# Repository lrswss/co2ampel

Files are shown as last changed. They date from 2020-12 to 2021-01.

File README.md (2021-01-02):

## CO2-Ampel

<p align="center">
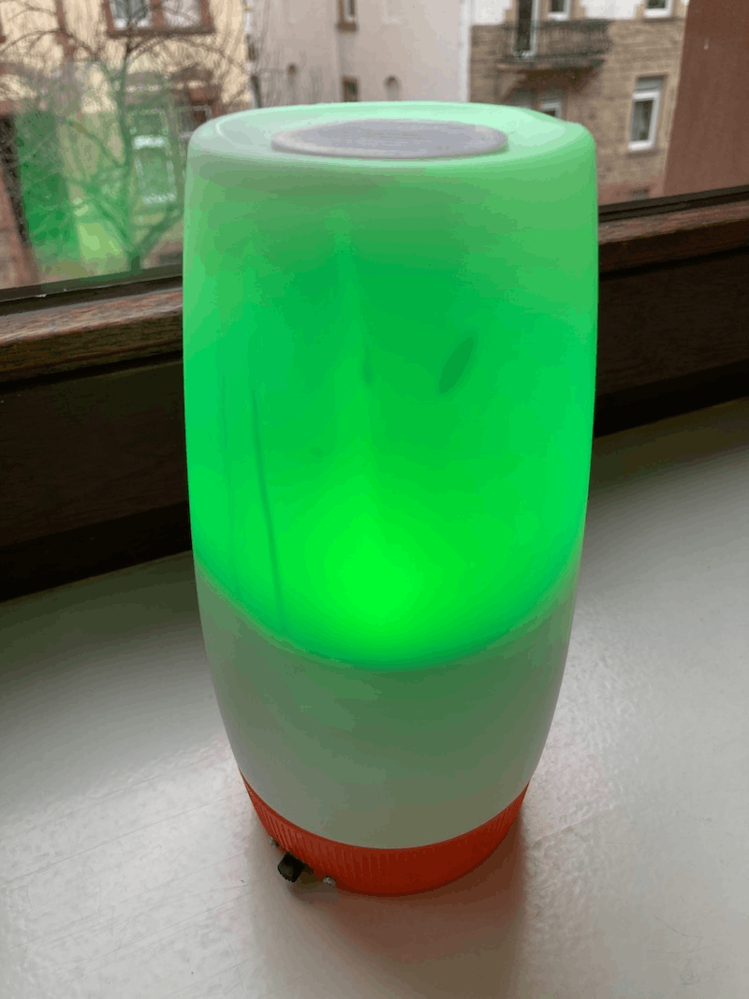
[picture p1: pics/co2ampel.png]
CO2Ampel

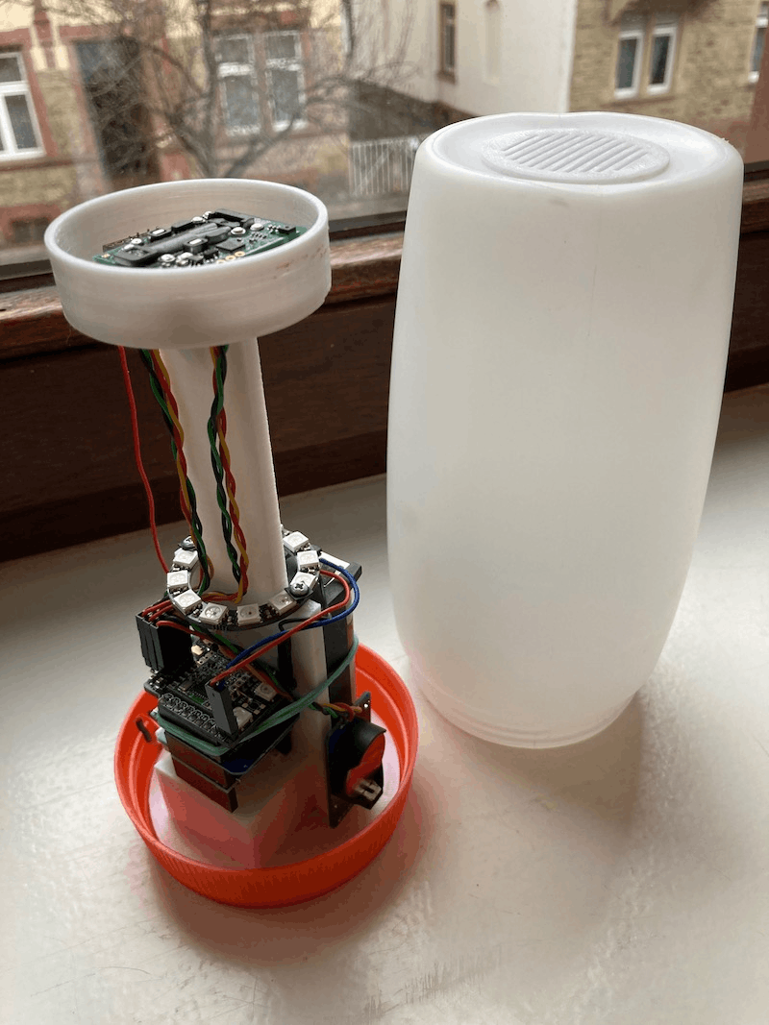
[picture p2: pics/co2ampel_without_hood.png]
CO2-Ampel disassembled (front)

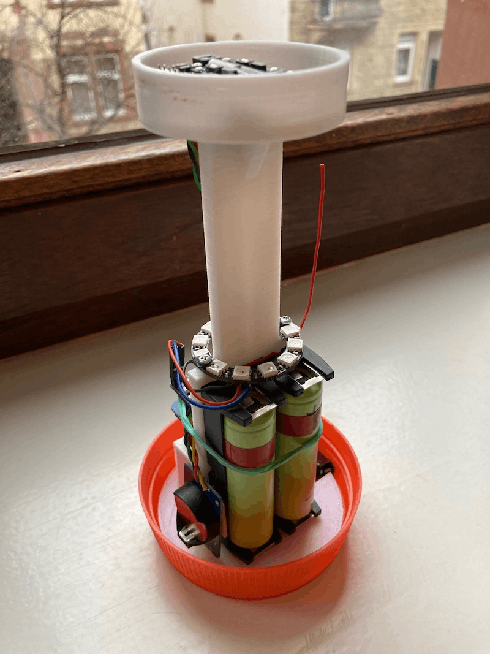
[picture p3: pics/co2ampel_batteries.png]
CO2-Ampel disassembled (back)

</p>

Yet another CO<sub>2</sub>-Ampel based on an ESP8266 (Wemos D1 mini) to continuously
measure CO<sub>2</sub> concentration indoors with a [SCD30](https://www.sensirion.com/en/environmental-sensors/carbon-dioxide-sensors/carbon-dioxide-sensors-CO<sub>2</sub>/) CO<sub>2</sub> sensor accompanied by a [BME280](https://www.bosch-sensortec.com/products/environmental-sensors/humidity-sensors-bme280/)
for temperature, humidity and air pressure readings. Current air condition
(good, medium, critical, bad) is shown using a NeoPixel ring with WS2812
LEDs illuminating the device in either green, yellow or red.

Unlike other devices this one runs on two 18650 Li-Ion batteries, offers
a sophisticated web interface for configuration, live sensor readings
and OTA firmware updates. Sensor data can be logged to local flash
(LittleFS), retrieved RESTful, published using MQTT or even transmitted
with LoRaWAN if a [RFM95 shield](https://github.com/hallard/WeMos-Lora)
is installed.

## Hardware components

* [SCD30 CO2 sensor](https://www.sensirion.com/en/environmental-sensors/carbon-dioxide-sensors/carbon-dioxide-sensors-CO<sub>2</sub>/)
* [BME280 break-out board](https://www.aliexpress.com/wholesale?SearchText=bme280&opensearch=true)
* [Wemos D1 mini board](https://escapequotes.net/esp8266-wemos-d1-mini-pins-and-diagram/)
* [Wemos Battery Shield](https://www.wemos.cc/en/latest/d1_mini_shield/battery.html)
* [Wemos ProtoBoard Shield](https://www.wemos.cc/en/latest/d1_mini_shield/protoboard.html) or
[LoRa Shield](https://github.com/hallard/WeMos-Lora)
* [DS3231 AT24C32 RTC Module](https://de.aliexpress.com/w/wholesale-ds3231.html)
* [NeoPixel ring with 12 WS2812 LEDs](https://www.aliexpress.com/w/wholesale-rgb%20led%20ring%2012%20bits%20ws2812.html)
* 3-pin slide switch
* 2 x 18650 rechargeable Li-Ion cells
* 2 x single-slot 18650 battery holders
* 5 x Dupont cables with female connector (3 x 4-pin, 1 x 2-pin, 1 x 1-pin)
* 2pin JST PH2.0 female plug
* 2.54mm single row pin headers for Dupont connectors

Looking around for a suitable housing for the CO<sub>2</sub>-Ampel we (my son and I)
spontaneously choose [this](https://www.ovomaltine.de/produkte/ovomaltine-pulver-dose)
because it was almost empty, pretty robust and seemed perfect in respect
to shape and size. :wink:

To help stack all components inside the translucent plastic tin I designed
a  simple [3D printed inner frame](3d-parts/inner-frame.png) which has a
place for all components and is  glued into the orange lid. The SCD30 and
BME280 sensors are placed into a seperate [3D printed sensor-mount](3d-parts/sensor-mount.png)
which is glued on top of the frame **after** the NeoPixel ring has been screwed
onto the frame. Air ventilation is achieved by a [3D printed grille](3d-parts/ventilation_grille.png)
pressed into a 40 mm hole cut into the rather thick bottom of the
plastic tin.

## Putting it all together

<p align="center">
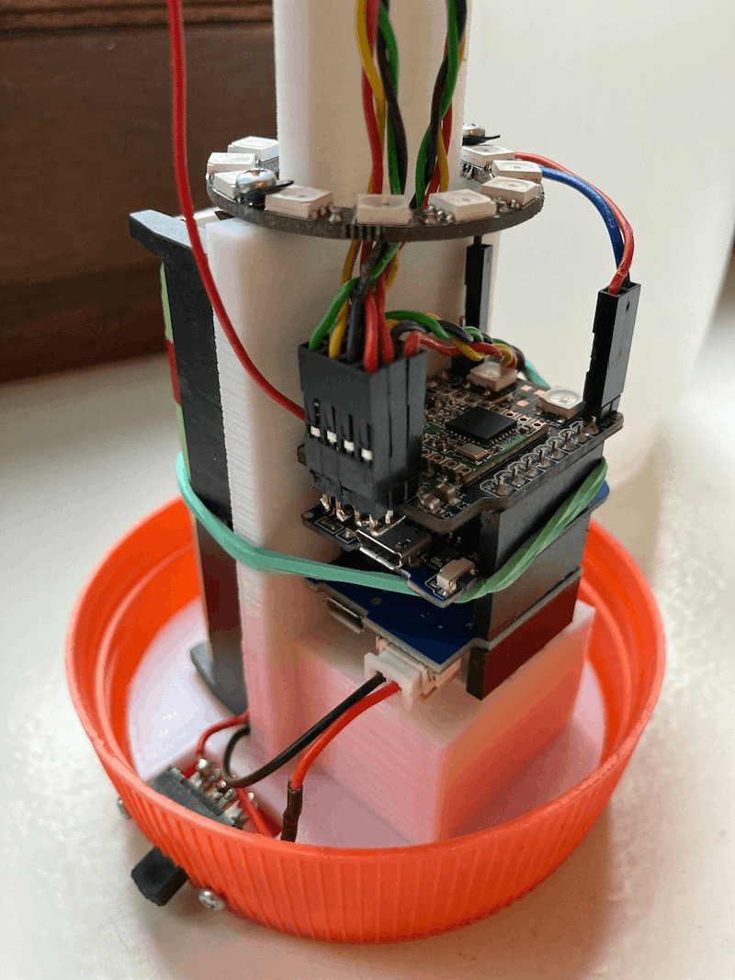
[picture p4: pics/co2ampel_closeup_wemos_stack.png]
CO2-Ampel with hood taken off

</p>

All Wemos components are simply stacked together. The battery shield is
placed at the bottom, the Wemos D1 mini in the middle and the (optional)
LoRa shield on top. The I2C connector of the LoRa shield was extended
with two more 4-pin headers to connect the three I2C modules (SCD30,
BME280, DS3231). Alternatively you can replace the LoRa shield with a
Wemos ProtoBoard shield and solder the three 4-pin headers in parallel
to D1 (SCL), D2 (SDA), 3.3V and GND on top of the board. If you're using
a ProtoBoard you also have to add two 4.7k pull-up resistors from D1 and D2
to 3.3V or I2C communication will proably fail.

The SCD30 CO<sub>2</sub> sensor, BME280 break-out board and DS3231 RTC are each
soldered to 4-pin Dupont cables which in turn connect to the 4-pin I2C
header on either the LoRa or a Wemos ProtoBoard shield. Double check
that all SCL pins are connected to D1 and all SDA pins to D2. The Vcc
input of all I2C modules **must** be connected to 3.3V of the Wemos stack
and **not 5V** or you'll destroy all I2C components in no time!

The Vin pin of the NeoPixel ring must be connected to 5V, its data input
port to GPIO0 and GND to GND of the Wemos shield stack. I used a 2-pin
Dupont cable for 5V and GPIO0 and a 1-pin cable for GND to connect the
ring to the 2.54mm pin headers soldered onto the LoRaWAN shield. If you're
using a Wemos ProtoBoard you probably want to merge GPIO0, 5V and GND
into a single 3-pin header.

The two 18650 battery holders are wired in parallel and are connected to
the Wemos battery shield using a JST PH2 female plug. A rubber band will
prevent the Li-Ion cells from becoming loose. The Vcc line is looped
through the slide switch mounted into the orange lid serving as the
external power switch.

Two 3400mAh Li-Ion cells will last for about two 9-to-5 working days. If
the voltage falls belows 3.55V the CO<sub>2</sub>-Ampel will enter deep sleep to
protect the cells from deep discharge. It will then wake up once every
hour, flash red six times before returning to deep sleep again. You can
configure a simple daily scheduler to adjust operating times to your needs.

The Li-Ion batteries can either be changed if empty or charged using the
micro usb port connected on the Wemos battery shield. On the bottom of
the battery shield you can choose to close a solder bridge (J1) to
increase charging current from 0.5A to 1A. Since only recent Wemos
battery shields (v1.3) offer a solder bridge (J2) to connect the battery
Vcc to A0 of the Wemos board (using a 120k resistor) you need to add
a resistor (100-220k) yourself from the Vcc pin of the JST male connector
on the shield to the A0 pin to enable voltage monitoring.

## Compiling the firmware

First adjust settings in `config.h` according to your needs (language) and hardware
setup. For an initial setup you should probably leave the default setttings
untouched since most of them can be changed anyway using the extensive
web interface and are then stored in the EEPROM of the DS3231 RTC module.
Only support for the optional [LoRa Shield](https://github.com/hallard/WeMos-Lora)
shield must be explicitly enabled by uncommenting `HAS_LORAWAN_SHIELD`.
Same holds true for the parameter `VBAT_ADJUST` which sets the multiplier
for the voltage divider used on the A0 input of the ESP8266 to measure
the battery voltage on the Wemos battery shield's JST battery connector.

Before trying to compile and flash the sketch to your Wemos D1 mini make
sure that you [added support for ESP8266 based boards](https://github.com/esp8266/Arduino)
and the following libraries have been installed. Don't be too intimidated
by the long list, the [Arduino IDE library manager](https://www.arduino.cc/en/Guide/Libraries)
will give you a hand. Make sure that you set the flash size to `4MB (FS:2MB OTA:~1019k)`
to spare flash for the logging. To save battery set the CPU-Frequency to `80 MHz`.

* [EPS8266Wifi](https://github.com/esp8266/Arduino/tree/master/libraries/ESP8266WiFi)
* [ESP8266WebServer](https://github.com/esp8266/Arduino/tree/master/libraries/ESP8266WebServer)
* [ESP8266HTTPUpdateServer](https://github.com/esp8266/Arduino/tree/master/libraries/ESP8266HTTPUpdateServer)
* [ESP8266mDNS](https://github.com/esp8266/Arduino/tree/master/libraries/ESP8266mDNS)
* [uEEPROMLib](https://github.com/Naguissa/uEEPROMLib)
* [RTClib](https://github.com/adafruit/RTClib)
* [FastLED](https://github.com/FastLED/FastLED)
* [PubSubClient](https://github.com/knolleary/pubsubclient/releases)
* [ArduinoJson](https://arduinojson.org/)
* [BME280I2C](https://github.com/finitespace/BME280)
* [MCCI LoRaWAN LMIC Library](https://github.com/mcci-catena/arduino-lmic)
* [LittleFS](https://github.com/esp8266/Arduino/tree/master/libraries/LittleFS)
* [NTPClient](https://github.com/arduino-libraries/NTPClient)
* [RunningMedian](https://github.com/RobTillaart/RunningMedian)
* [Time](https://github.com/PaulStoffregen/Time)
* [Timezone](https://github.com/JChristensen/Timezone)

You only need to upload the firmware from the Arduino IDE to the Wemos D1 mini
using its micro USB connector once. For further updates just use the *Export compiled
Binary* option under the *Sketch* menu in the Arduino  IDE and upload the binary
using the firmware update option in the web interface.

## Initial startup

After flashing the firmware onto a hopefully working hardware setup you
should enable the serial monitor in the Arduino IDE to closely monitor
the startup process and initial operation of the CO<sub>2</sub>-Ampel.

Right after power up you'll see two white flashes inidicating a successful
inialization of all components connected to the I2C bus, followed by two
green flashes showing a successful initialization of the RTC module. An
error at this stage will result in continous red flashing...time to check
all connections.

If you compiled in support for the optional LoRa shield and also enabled
OTAA by defining `LORAWAN_USEOTAA` in `config.h` the CO<sub>2</sub>-Ampel will now
try to connect to a LoRaWAN gateway with a timeout of 10 seconds. During
OTAA it will flash magenta followed be two green flashes if the network
join succeeded. LoRaWAN session keys and settings are stored in EEPROM
and reused on next power up. An OTAA failure will trigger two red flashes.

Next WiFi is turned on (two blue flashes), a local access point is fired
up (two green flashes) and a webserver is started to further configure
the devices and show current sensor readings. If you enabled the optional
WiFi uplink in `config.h` a few LEDs will now turn blue while trying
to connect to the WiFi network specified with `WIFI_STA_SSID` and
`WIFI_STA_PASSWORD`. On success you'll see two green flashes otherwise
red. You need to connect the CO<sub>2</sub>-Ampel to a local WiFi (with internet
access) at least once to initially set its RTC.

If a WiFi uplink is available and MQTT is enabled the CO<sub>2</sub>-Ampel will
initially connect to the configured MQTT broker. A successlful
initialization of the MQTT uplink is indicated by two orange flashes.

The initial setup ends with a few more green flashes indicating the
successful initialization of the SCD30 and BME280 sensor modules. At
last the CO<sub>2</sub>-Ampel will switch to white for about a minute giving the
SCD30 time to warm up. Eventually monitoring of the CO<sub>2</sub> concentration
will start indicated by a continous green (good), yellow (medium) or
red (bad) illumination. If you start to see two repeating red flashes
the air condition is critical...time to open the windows!

Continous four red flashes indicate repeated errors while trying to
get valid CO<sub>2</sub> readings from the SCD30 sensor. Turning the
CO<sub>2</sub>-Ampel off for a few seconds will usually fix this.

If the reset button on the Wemos D1 mini is pressed all settings are
reset to their default values as set in `config.h` at compile time.

## Adjust device settings

<p align="center">
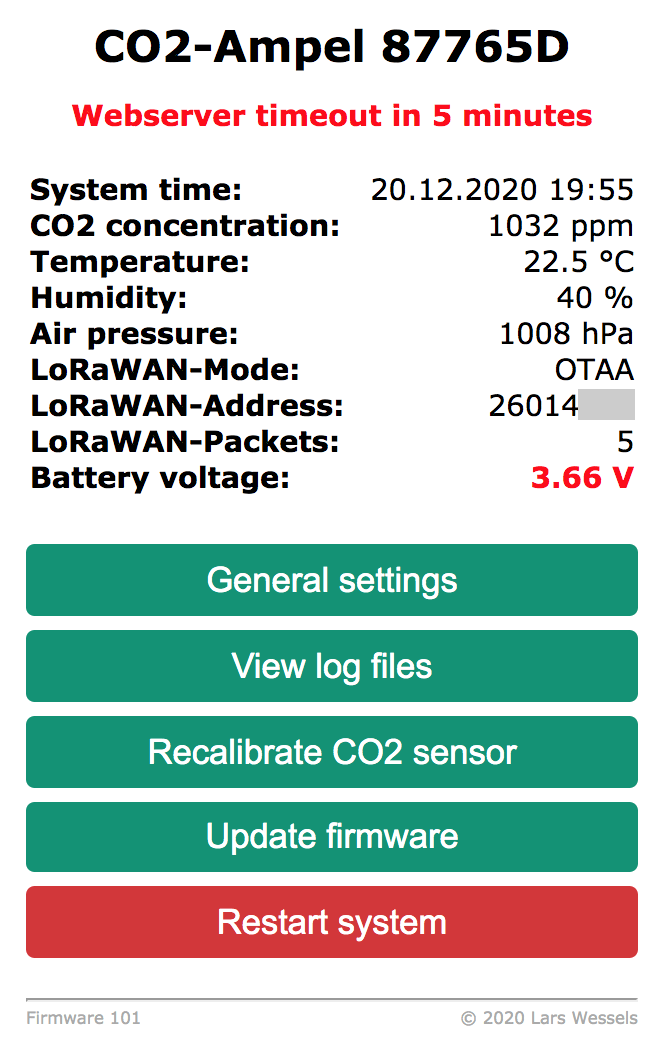
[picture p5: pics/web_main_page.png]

</p>

During the initial setup phase the CO<sub>2</sub>-Ampel will start a WiFi access
point with the SSID `CO2-Ampel` followed by six alphanumeric characters
derived from the Wemos D1 mini's MAC address. You can connect to the access
point within a timeout initilially set to 10 minutes using the password
specified by `WIFI_AP_PASSWORD` (default is `__mysecret__`). Then point
your favorite browser to `http://192.168.4.1` and you'll be presented an
extensive web interface to further configure your CO<sub>2</sub>-Ampel.
Its language is preset at compile time by either defining `LANG_DE` or
`LAND_EN` in `config.h`. All settings are saved in the EEPROM of the RTC
module and will thus survive a power off.

## CO2 sensor calibration

Since the SCD30 CO<sub>2</sub> sensor has to be exposed to fresh air for at least
one hour every day to make its automatic self-calibration (ASC) work as
expected, it has been disabled in this setup. The SCD30 is pre-calibrated
at the factory, but the accuracy (approx. +- 60 ppm, drift approx. 80 ppm/year)
may change e.g. due to mechanical effects during transport.

However the CO<sub>2</sub> sensor can be manually (re)calibrated in fresh air (outdoor
air is actually between 350 ppm and 450 ppm in normal geographic locations)
using its forced recalibration (FRC) command which can be triggered in the
web interface. Just place the CO<sub>2</sub>-Ampel into (windless) fresh air, start
the calibration process (CO<sub>2</sub>-Ampel will switch to cyan color) and keep an
eye on the web interface. The fully automated calibration might take a few
minutes since the CO<sub>2</sub>-Ampel now continously monitors the standard deviation
of the CO<sub>2</sub> readings. It will only set a new reference value (410 ppm) if
the readings are more or less stable. This value can be changed in `sensor.h`
with `SCD30_CO2_CALIBRATION_VALUE`.

If CO<sub>2</sub> readings still keep floating within a timeout of 5 minutes the
calibration is eventually aborted, keeping the previous reference value.
The CO<sub>2</sub>-Ampel will flash red for 15 seconds to indicate calibration failure.

The temperature offset between the onboard RH/T sensor and the BME280 is
continously corrected automatically based on their standard deviation.
Intial offset is set to 1.9 in `sensors.h` with `SCD30_TEMP_OFFSET`.

## Disclaimer

Even though this device consists more or less of the same components as professional
systems it does not have any certification. It's a home made product for
educational purposes and thus cannot be used as medical device or serve
as personal protective equipment in the sense of any legislation.

## Contributing

Pull requests are welcome! For major changes, please open an issue first to
discuss what you would like to change.

## License

Copyright (c) 2020-2021 Lars Wessels  
This software was published under the Apache License 2.0.  
Please check the [license file](LICENSE).

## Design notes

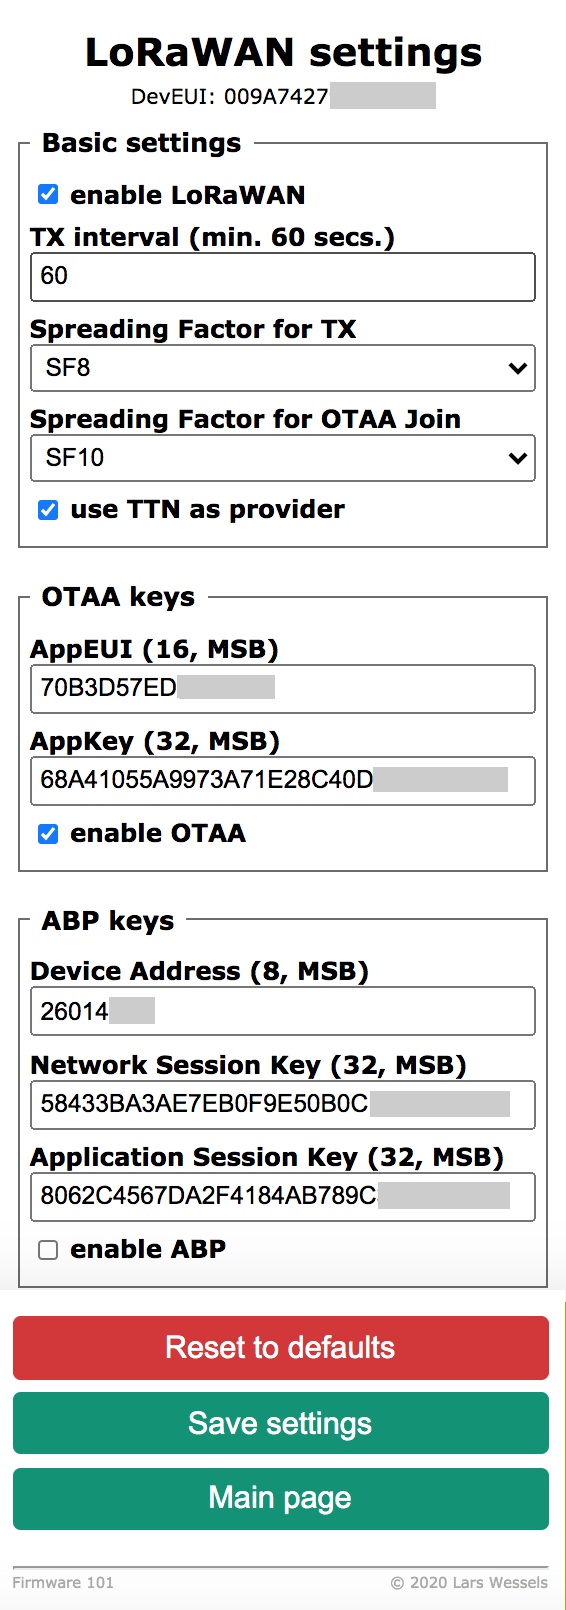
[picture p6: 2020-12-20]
pics/web_lorawan_settings.png

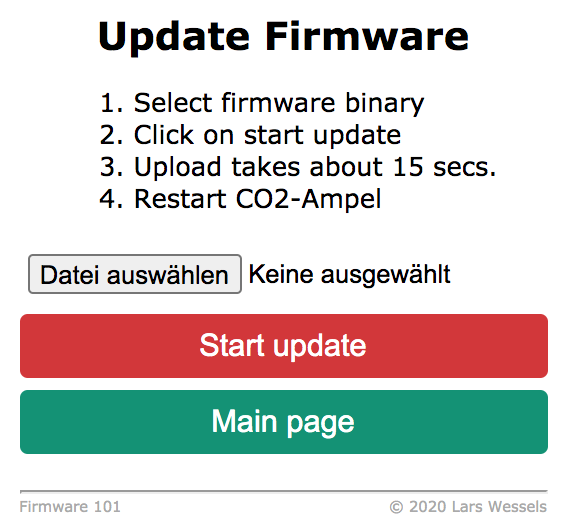
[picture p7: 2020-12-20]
pics/web_firmware_update.png

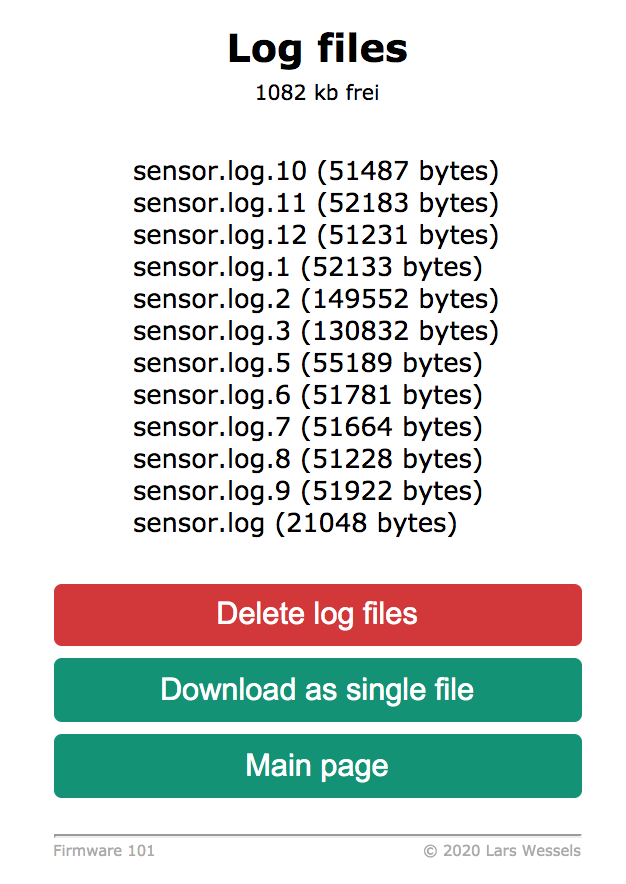
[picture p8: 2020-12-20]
pics/web_log_files.png

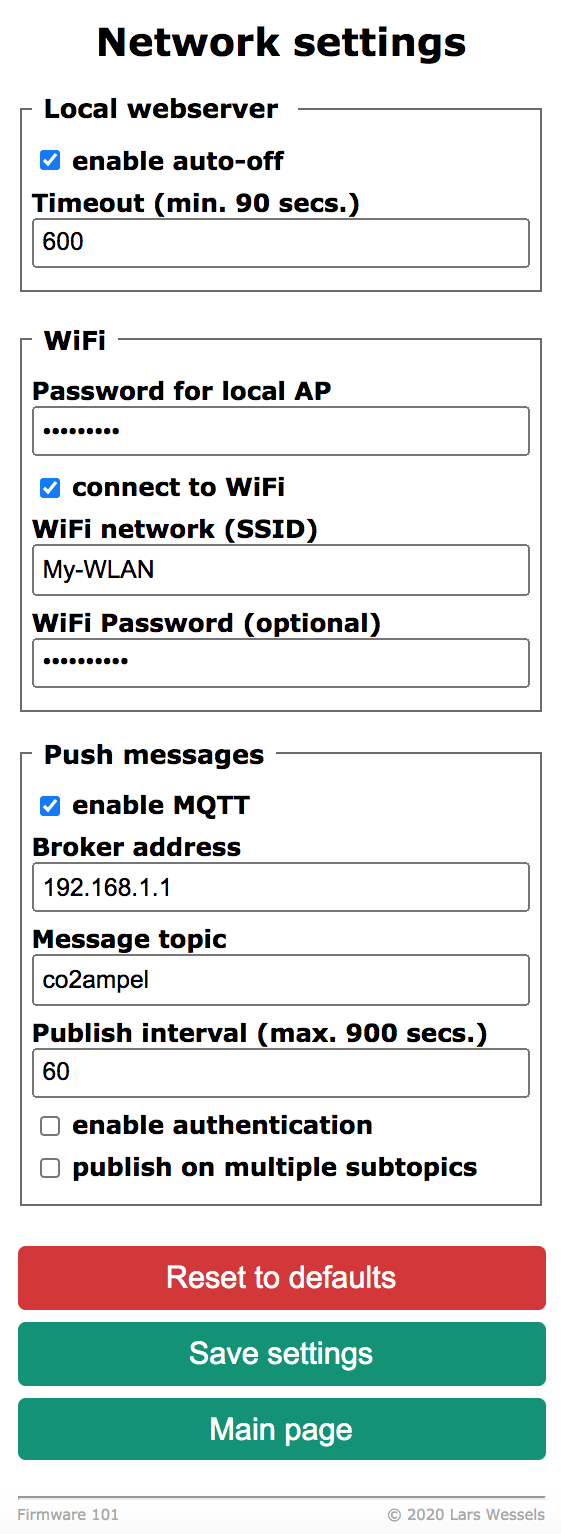
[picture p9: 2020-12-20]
pics/web_network_setttings.png

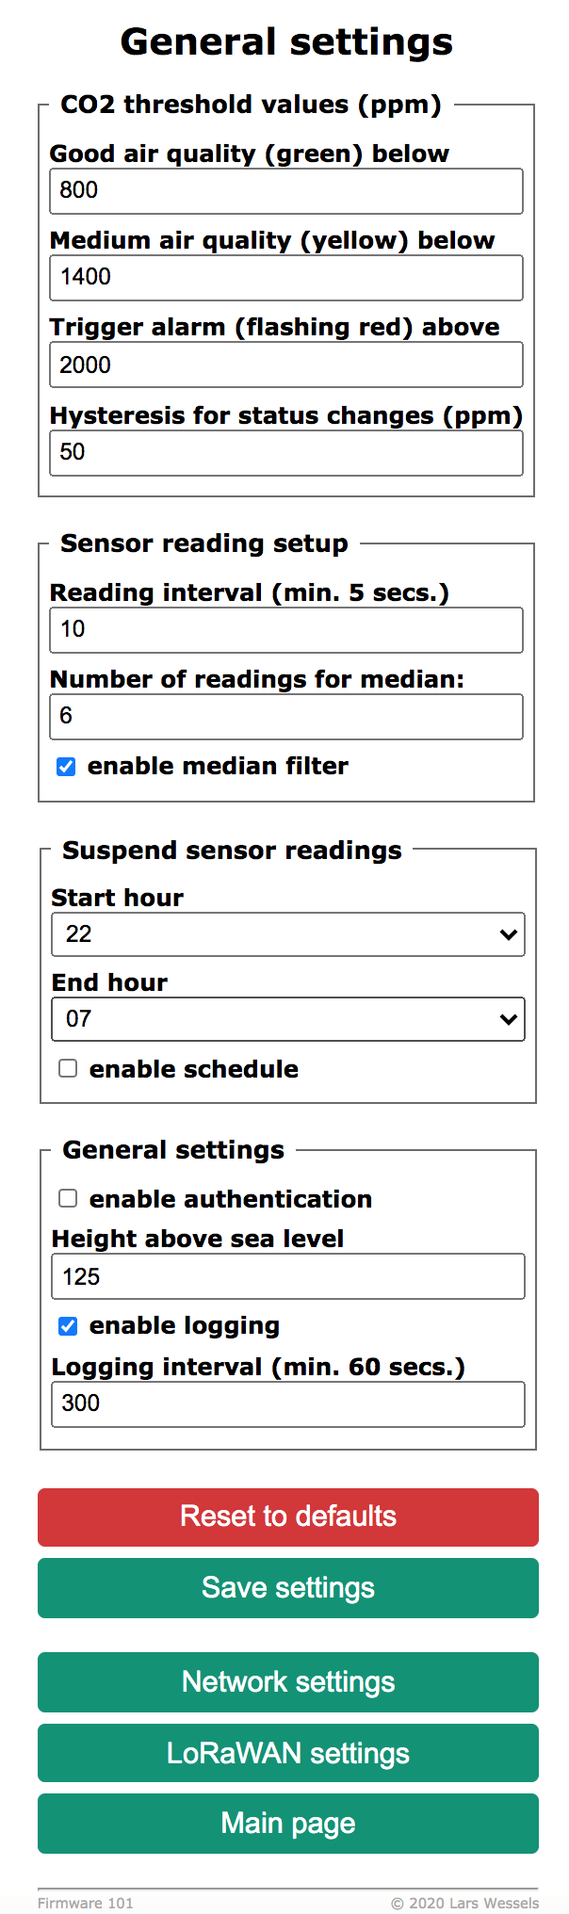
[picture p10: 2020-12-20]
pics/web_general_settings.png

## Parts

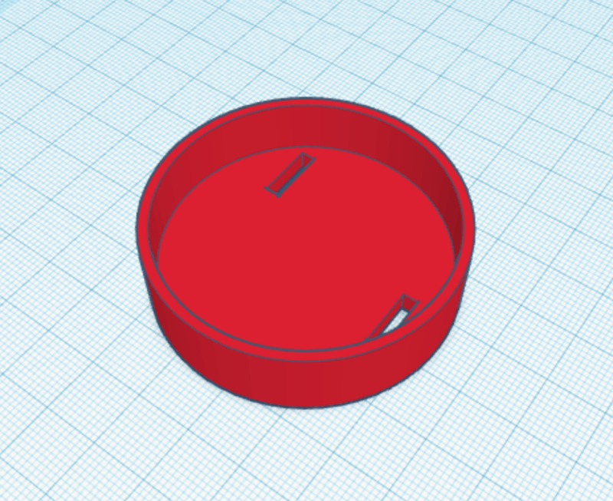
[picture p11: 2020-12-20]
3d-parts/sensor-mount.png

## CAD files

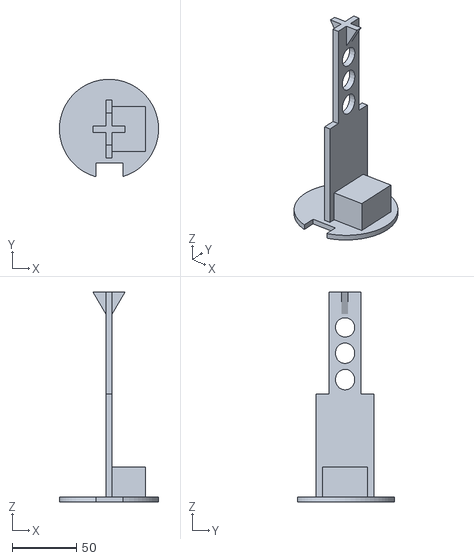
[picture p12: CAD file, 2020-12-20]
3d-parts/inner-frame.stl
77.0 x 75.6 x 163.0

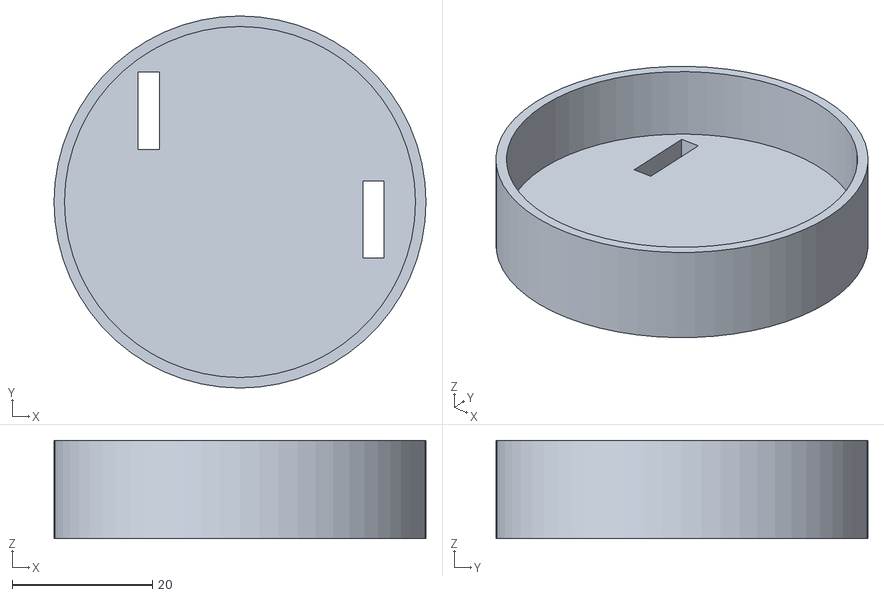
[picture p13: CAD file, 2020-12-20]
3d-parts/sensor-mount.stl
53.0 x 53.0 x 14.0

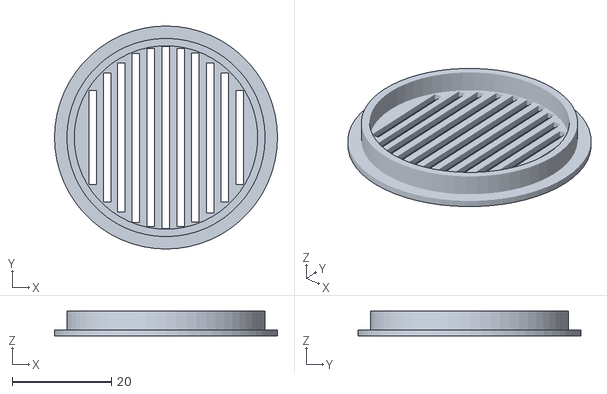
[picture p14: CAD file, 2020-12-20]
3d-parts/ventilation-grille.stl
45.0 x 45.0 x 5.00

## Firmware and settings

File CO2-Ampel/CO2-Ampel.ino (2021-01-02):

/*******************************************************************************

  Copyright (c) 2020-2021 Lars Wessels

  Yet another "CO2-Ampel" based on an ESP8266 (Wemos D1 mini) to continuously
  measure CO2 concentration indoor with a SCD30 sensor accompanied by a BME280
  for temperature, humidity and air pressure readings. Current air condition
  (good, medium, critical, bad) is shown using a NeoPixel ring with WS2812
  LEDs illuminating the device in either green, yellow or red.

  Unlike other devices this one runs on two 18650 LiIon-batteries, offers a
  sophisticated web interface for configuration, live sensor readings and
  OTA firmware updates. Sensor data can be logged to local flash (LittleFS),
  retrieved RESTful, published using MQTT or transmitted with LoRaWAN if a
  RFM95 shield is installed.


  Licensed under the Apache License, Version 2.0 (the "License"); you may 
  not use this file except in compliance with the License. You may obtain 
  a copy of the License at http://www.apache.org/licenses/LICENSE-2.0

  Unless required by applicable law or agreed to in writing, software
  distributed under the License is distributed on an "AS IS" BASIS, WITHOUT 
  WARRANTIES OR CONDITIONS OF ANY KIND, either express or implied. See the 
  License for the specific language governing permissions and limitations 
  under the License.

 *******************************************************************************/

#include "config.h"
#include "led.h"
#include "rtc.h"
#include "sensors.h"
#include "webserver.h"
#include "wifi.h"
#include "logging.h"
#include "lorawan.h"
#include "mqtt.h"
#include "utils.h"


void setup() {
  Serial.begin(115200);
  delay(500);
  char buf[32];

  Serial.println();
  Serial.printf("%s (v%d)\n", "CO2-Ampel-BME280-LoRaWAN-MQTT-RESTful", FIRMWARE_VERSION);

  bootMessage();
  led_init();
  mountFS();

  sprintf(buf, "%s,v%d", runmodes[runmode], FIRMWARE_VERSION);
  logMsg(buf);
  
  pinMode(A0, INPUT);
  checkLowBat();
   
  // initialize I2C bus and check for (right) number of devices
  if (i2c_init() != 4) { // SCD30, BME280, DS3231, EEPROM
    Serial.println(F("I2C bus error...system halted!"));
    while (1) {
      logMsg("i2c error");
      blink_leds(ALL_LEDS, RED, 500, 1, false);
      delay(2000);
    }
  } else {
    blink_leds(HALF_RING, WHITE, 500, 2, false);
    delay(1000);
  }

  // reset button will clear system settings
  if (runmode == RESET) {
    logMsg("reset button");
    resetGeneralSettings();
    resetMQTTSettings();
    resetWifiSettings();
  } else {
    // load general settings from DS3231 EEPROM (24C32)
    loadGeneralSettings();
  }
  
  // check for power saving NOOP mode (requires valid RTC time)
  // in NOOP mode only webserver and MQTT are enabled (optional)
  checkNOOPTime(settings.beginSleep, settings.endSleep);

  // recommended: https://github.com/hallard/WeMos-Lora
#ifdef HAS_LORAWAN_SHIELD
  if (runmode == RESET) {
    resetLoRaWANSettings();
    resetLoRaWANSession();
  } else {
    loadLoRaWANSettings();
  }
  if (lorawanSettings.enabled && co2status != NOOP) {
    lmic_init(); // might trigger a (blocking) join request
  } else if (!lorawanSettings.enabled) {
    Serial.println(F("LoRaWAN disabled."));
    logMsg("lorawan disabled");
  }
#endif

  // always start an AP and fire up local webserver with (optional) timeout
  // to allow access to system settings or we'd be locked out until NOOP
  // time has finished...
  loadWifiSettings();
  wifi_hotspot(false);
  webserver_start((co2status == NOOP && runmode != RESET) ? WEBSERVER_TIMEOUT_NOOP : wifiSettings.webserverTimeout);

  // try to connect to local WiFi to update RTC and send push MQTT messages
  if (wifiSettings.enableWLANUplink) {
    wifi_uplink(true);
    startNTPSync();
  }
  Serial.printf("Local time (RTC): %s, %s\n", getDateString(), getTimeString(true));
  
  loadMQTTSettings();
  if (wifiSettings.enableWLANUplink && mqttSettings.enabled) {
    mqtt_send(500); // send initial alive message after system startup
  } else if (!mqttSettings.enabled) {
    Serial.println(F("MQTT disabled."));
    logMsg("mqtt disabled");
  } else {
    Serial.println(F("MQTT: no WiFi uplink, disabled."));
    logMsg("mqtt disabled (no wifi)");
  }

  if (co2status != NOOP) {
    sensors_init();
    rotateLogs();
    Serial.println(F("Setup completed.\n"));
  } else {
    // sensors are disabled in NOOP mode
    Serial.print(F("System will power down in "));
    if (runmode != RESET)
      Serial.print(WEBSERVER_TIMEOUT_NOOP);
    else
      Serial.print(wifiSettings.webserverTimeout);
    Serial.println(F(" secs...\n"));
  }
}


void loop() {
  static uint32_t failureStateSecs, failureCountdown, runtimeCounterSecs = 1;
  static uint32_t prevSecond, prevReadings = millis()/1000;

  // check for webserver timeout and handle browser requests
  if (!webserver_stop(false))
    webserver.handleClient();

  // initial warmup for scd30 co2 sensor
  if (millis()/1000 <= SCD30_WARMUP_SECS) {
    if (co2status == NODATA) {
      Serial.print(F("System warm up, starting periodic sensor readings in "));
      Serial.print(SCD30_WARMUP_SECS - millis()/1000);
      Serial.println(F(" seconds..."));
      co2status = WARMUP;
      set_leds(HALF_RING, WHITE);
      scd30_warmup_countdown = SCD30_WARMUP_SECS - int(millis()/1000);
      logReadings(runtimeCounterSecs);
    }

  // do not query sensors in state CALIBRATE, FAILURE or NOOP
  } else if (co2status < CALIBRATE && 
      (millis()/1000 - prevReadings >= max(5, int(settings.co2ReadingInterval)))) { // lower limit 5 sec.
    prevReadings = millis()/1000;
    //rtc_temperature();
    bme280_readings(true);
    if (scd30_readings(false)) {
      if (scd30_co2ppm < CO2_LOWER_BOUND) {
        if (co2status != NODATA) {
          co2status = NODATA;
          logReadings(runtimeCounterSecs); // don't switch color, just log intermediate failed readings
        }   
      } else if ((co2status <= GOOD && scd30_co2ppm <= settings.co2MediumThreshold) ||
          (co2status == MEDIUM && (scd30_co2ppm + CO2_THRESHOLD_HYSTERESIS) <= settings.co2MediumThreshold)) {
        if (co2status != GOOD) {
          set_leds(QUARTER_RING, GREEN);
          co2status = GOOD;
          logReadings(runtimeCounterSecs);
        }
      } else if ((co2status <= MEDIUM && scd30_co2ppm <= settings.co2HighThreshold) ||
          (co2status == CRITICAL && (scd30_co2ppm + CO2_THRESHOLD_HYSTERESIS) <= settings.co2HighThreshold)) {
        if (co2status != MEDIUM) {
          set_leds(HALF_RING, YELLOW);
          co2status = MEDIUM;
          logReadings(runtimeCounterSecs);
        }
      } else if ((co2status <= CRITICAL && scd30_co2ppm <= settings.co2AlarmThreshold) ||
          (co2status == ALARM && (scd30_co2ppm + CO2_THRESHOLD_HYSTERESIS) <= settings.co2AlarmThreshold)) {
        if (co2status != CRITICAL) {
          set_leds(HALF_RING, RED);
          co2status = CRITICAL;
          logReadings(runtimeCounterSecs);
        }
      } else if (co2status != ALARM) {
          co2status = ALARM;
          logReadings(runtimeCounterSecs);

      }
      Serial.printf("Condition: %s\n", statusNames[co2status]);

    } else if (co2status != FAILURE) {
        co2status = FAILURE;
        Serial.println(F("Switching to state FAILURE!"));
        logMsg("system failure");
        clear_leds(FULL_RING);
        logReadings(runtimeCounterSecs);
    }
  }

  // main control loop for periodic actions
  if (millis() - prevSecond >= 1000) { // once every seconds
    prevSecond = millis();

    // stop local AP if webserver has stopped
    if (webserver_stop(false))
      wifi_hotspot(true);

    // switch off wifi after webserver timeout unless MQTT push is enabled
    if (!mqttSettings.enabled && webserver_stop(false) && wifi_uplink(false)) {
      stopNTPSync();
      wifi_stop();
    }

    if (co2status == NOOP && !settings.enableNOOP) {
      // if currently active NOOP mode has just been disabled in webui, 
      // reset webserver timeout, fire up all sensors and enable LoRaWAN
      webserver_settimeout(wifiSettings.webserverTimeout);
      sensors_init();
#ifdef HAS_LORAWAN_SHIELD
      if (lorawanSettings.enabled)
        lmic_init();
#endif
    }

    // check for NOOP and enter deep sleep
    if (!(runtimeCounterSecs % 10)) {
      checkNOOPTime(settings.beginSleep, settings.endSleep);
      if (co2status == NOOP) {
        webserver_settimeout(WEBSERVER_TIMEOUT_NOOP);
        if (webserver_stop(false)) { // wait for webserver to terminate
          if ((getHourLocal() == settings.endSleep-1) || (getHourLocal() == 23 && !settings.endSleep))
            enterDeepSleep((60-rtc.now().minute())*60);
          else if (getHourLocal() == settings.endSleep)
            // triggered on race condition (system wake up few seconds before endSleep hour)
            // need to enforce a restart; only way to leave NOOP is to re-run setup()
            enterDeepSleep(10);
          else
            enterDeepSleep(3600);
        }
      }
    }

    // skip sensor readings, logging, LoRaWAN transmissions
    // and MQTT push messages when in NOOP mode
    if (co2status != NOOP) {

      if (!(runtimeCounterSecs % mqttSettings.pushInterval)) {
        if (mqttSettings.enabled) {
          if (wifi_uplink(true)) { // reconnect if necessary
            mqtt_send(500);  // will implicitly call mqtt_init()
          } else {
            Serial.println("MQTT: no WiFi uplink, cannot publish readings.");
            logMsg("mqtt failed (no wifi)");
            mqtt_stop();
          }
        } else {
          mqtt_stop();
        }
      }

      // log current sensor readings and check battery
      if (settings.enableLogging && co2status != WARMUP &&
          !(runtimeCounterSecs % settings.loggingInterval)) {
        checkLowBat();
        Serial.print(F("Runtime: "));
        Serial.println(getRuntime(runtimeCounterSecs));
        logReadings(runtimeCounterSecs);
      }

#ifdef HAS_LORAWAN_SHIELD
      if (!(runtimeCounterSecs % 10) && webserver_idle() > 5000) {
        if (lorawanSettings.enabled && !lmic_ready())
          lmic_init();
        else if (!lorawanSettings.enabled && lmic_ready())
          lmic_stop();
      }
      if (lorawanSettings.enabled && !(runtimeCounterSecs % lorawanSettings.txInterval)) {
        if (lmic_ready() && co2status > WARMUP && co2status < CALIBRATE) {
          lmic_send(&lorawanjob);
          waitForLorawanJobs(5, false); // blocking
        }
      }
#endif

      if (scd30_warmup_countdown > 1)
        scd30_warmup_countdown--;

      if (!(runtimeCounterSecs % SCD30_OFFSET_UPDATES_SECS)) {
        scd30_pressure(bme280_pressure);
        scd30_adjustTempOffset();
      }

      // check for log rotation every hour
      if (settings.enableLogging && !(runtimeCounterSecs % 3600))
        rotateLogs();

    } // end !NOOP

    // blinking on ALARM, CALIBRATE, ERROR or NOOP status
    if (co2status >= ALARM) {
      if (leds_on() > 0) {
        if (co2status == NOOP) {
          blink_leds(QUARTER_RING, BLUE, 250, 1, false);

        } else if (co2status == ALARM) {
          blink_leds(HALF_RING, RED, 250, 2, false);
          
        } else if (co2status == FAILURE) {
          blink_leds(HALF_RING, RED, 100, 4, false);
          webserver_start(600); // offer maintenance
          
          if (failureCountdown) // temporarily triggered by calibration failure
            if (!--failureCountdown)
              co2status = NODATA;
              
          if (!failureStateSecs)
            failureStateSecs = millis()/1000;
          if (millis()/1000 - failureStateSecs >= 600)  // 10 min.
            // eventually restart system, might resolve problem
            resetSystem(); 
            
        } else if (co2status == CALIBRATE) {
          blink_leds(HALF_RING, CYAN, 250, 2, false);
          webserver_tickle();
          scd30_calibrate(SCD30_CALIBRATION_SECS);
          if (co2status == FAILURE)
            failureCountdown = 15; // leave failure status after 15 secs
        }
      } else {
        clear_leds(FULL_RING);
      }
    }
    runtimeCounterSecs++;
  }
}

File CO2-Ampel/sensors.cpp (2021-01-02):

/***************************************************************************
  Copyright (c) 2020-2021 Lars Wessels

  This file a part of the "CO2-Ampel" source code.
  https://github.com/lrswss/co2ampel

  Published under Apache License 2.0

***************************************************************************/

#include "sensors.h"
#include "led.h"
#include "logging.h"
#include "rtc.h"
#include "utils.h"
#include "config.h"

float scd30_temperature;
uint16_t scd30_co2ppm;
uint8_t scd30_humidity;
int16_t scd30_calibrate_countdown;
int16_t scd30_warmup_countdown;
float bme280_temperature;
uint8_t bme280_humidity;
uint16_t bme280_pressure;
bool hasBME280 = false;
static bool scd30Init = false;
static bool bme280Init = false;
sensorStatus co2status;

char statusNames[9][10] = {
   "nodata",
   "warmup",
   "good",
   "medium",
   "critical",
   "alarm",
   "calibrate",
   "failure",
   "noop"
 };

BME280I2C bme;
SCD30 airsensor;
uEEPROMLib eeprom(0x57);
RunningMedian scd30_co2_readings = RunningMedian(settings.co2MedianSamples);
RunningMedian scd30_co2_calibrate = RunningMedian(15);
RunningMedian scd30_temp_readings = RunningMedian(9);
RunningMedian bme280_temp_readings = RunningMedian(9);


// returns standard deviation of given running median readings
static float stdDev(RunningMedian readings, bool debug) {
  int32_t average = 0;
  uint32_t sqDevSum = 0.0;
  float deviation;

  if (readings.getCount() < 5)
    return UCHAR_MAX;
  
  average = int(readings.getAverage()*100);
  for(uint8_t i = 0; i < readings.getCount(); i++) {
      sqDevSum += pow((average - (readings.getElement(i)*100)), 2);
  }
  deviation = sqrt(sqDevSum/readings.getCount())/100;

  if (debug) {
    Serial.print(F("Values: "));
    for (uint8_t i = 0; i < readings.getCount(); i++) {
      Serial.print(readings.getElement(i));
      Serial.print(" ");
    }
    Serial.println();
    Serial.print(F("Mean: " ));
    Serial.println(average/100.0);
    Serial.print(F("Sigma: "));
    Serial.println(deviation);
  }

  return deviation;
}


// start BME280 and SCD30 sensors
void sensors_init() {
  bme280_init();
  bme280_readings(true);
  scd30_init(bme280_pressure);
  co2status = NODATA;
}


// initaliaze BME-Sensor and return current pressure
uint16_t bme280_init() {
  if (!bme.begin()) {
    Serial.println(F("Couldn't find BME280 sensor...system halted!"));
    logMsg("bme280 error");
    while (1) {
      blink_leds(HALF_RING, RED, 500, 3, false);
      delay(2000);
    }
  }

  switch (bme.chipModel()) {
    case BME280::ChipModel_BME280:
      Serial.println(F("Found BME280 sensor."));
      hasBME280 = true;
      break;
    case BME280::ChipModel_BMP280:
      Serial.println(F("Found BMP280 sensor."));
      break;
    default:
      Serial.println(F("Found UNKNOWN sensor."));
      while (1) {
        blink_leds(HALF_RING, RED, 500, 4, false);
        delay(2000);
      }
  }
  bme280Init = true;
  blink_leds(SYSTEM_LEDS, GREEN, 100, 2, false);
  delay(1000);
}


void scd30_init(uint16_t pressure) {
  static char buf[64], s[8];
  uint8_t interval;
      
  if (!airsensor.begin(false)) {  // disable auto calibration
    Serial.println(F("Couldn't find scd30 air sensor...system halted!"));
    logMsg("scd30 error");
    while (1) {
      blink_leds(HALF_RING, RED, 500, 5, false);
      delay(2000);
    }
  } else {
    interval = max(3, int(settings.co2ReadingInterval/2));
    Serial.println(F("Found SCD30 air sensor.")); 
    Serial.print(F("SCD30: auto-calibration disabled, reading interval set to "));
    Serial.print(interval);
    Serial.print(F(" secs"));
    sprintf(buf, "scd30 reading interval %d secs", interval);
    if (!airsensor.setMeasurementInterval(interval)) {
      Serial.println(F(" [FAILED]"));
      strcat(buf, " failed");
    }
    Serial.println();
    logMsg(buf);
    
#ifdef ALTITUDE_ABOVE_SEELEVEL
    Serial.print(F("SCD30: set altitude compensation to "));
    Serial.print(settings.altitude);
    Serial.print("m");
    sprintf(buf, "scd30 altitude compensation %dm", settings.altitude);
    if (!airsensor.setAltitudeCompensation(settings.altitude)) {
      Serial.println(F(" [FAILED]"));
      strcat(buf, " failed");
    }
    Serial.println();
    logMsg(buf);
#endif

    if ((pressure > 850) && (pressure < 1050)) {
      Serial.print(F("SCD30: setting ambient pressure to "));
      Serial.print(pressure);
      Serial.print(F("hPa"));
      sprintf(buf, "scd30 ambient pressure %dhPa", pressure);
      if (!airsensor.setAmbientPressure(pressure)) {
        Serial.println(F(" [FAILED]"));
        strcat(buf, " failed");
      }
      Serial.println();
      logMsg(buf);
    }

    airsensor.setTemperatureOffset(settings.scd30TempOffset);
    Serial.print(F("SCD30: temperature offset is "));
    Serial.print(airsensor.getTemperatureOffset(), 2);
    Serial.println();
    dtostrf(airsensor.getTemperatureOffset(), 5, 2, s);
    sprintf(buf, "scd30 temperature offset %s", removeSpaces(s));
    logMsg(buf);
  }
  scd30Init = true;
  blink_leds(SYSTEM_LEDS, GREEN, 100, 2, false);
  delay(1000);
}


// increase measurement interval to 120 sec. to save power
void scd30_sleep() {
  if (!scd30Init)
    airsensor.begin(false);
  airsensor.setMeasurementInterval(120);
}
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

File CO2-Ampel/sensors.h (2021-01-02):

/***************************************************************************
  Copyright (c) 2020-2021 Lars Wessels

  This file a part of the "CO2-Ampel" source code.
  https://github.com/lrswss/co2ampel

  Published under Apache License 2.0

***************************************************************************/

#ifndef _SENSORS_H
#define _SENSORS_H

#include "SparkFun_SCD30_Arduino_Library.h"
#include <BME280I2C.h>
#include <Wire.h>
#include <RunningMedian.h>

#define SCD30_CO2_CALIBRATION_VALUE 420
#define SCD30_CALIBRATION_SECS 300
#define SCD30_TEMP_OFFSET 1.9
#define SCD30_OFFSET_UPDATES_SECS 600
#define SCD30_INTERVAL_MIN_SECS 5
#define SCD30_INTERVAL_MAX_SECS 60 // see CD_AN_SCD30_Low_Power_Mode_D2.pdf
#define SCD30_WARMUP_SECS 60
#define SCD30_READING_TIMEOUT 90
#define CO2_LOWER_BOUND 350  // https://wiki.seeedstudio.com/Grove-CO2_Sensor/


enum sensorStatus {
  NODATA,
  WARMUP,
  GOOD,
  MEDIUM,
  CRITICAL,
  ALARM,
  CALIBRATE,
  FAILURE,
  NOOP
};

extern uint16_t scd30_co2ppm;
extern float scd30_temperature;
extern uint8_t scd30_humidity;
extern int16_t scd30_calibrate_countdown;
extern int16_t scd30_warmup_countdown;
extern float bme280_temperature;
extern uint16_t bme280_pressure;
extern uint8_t bme280_humidity;
extern bool hasBME280;
extern sensorStatus co2status;
extern char statusNames[9][10];

extern BME280I2C bme;
extern SCD30 airSensor;
extern RunningMedian scd30_co2_readings;

void sensors_init();
uint16_t bme280_init();
void bme280_readings(bool verbose);
void scd30_init(uint16_t pressure);
void scd30_sleep();
bool scd30_readings(bool reset);
void scd30_pressure(uint16_t pressure);
void scd30_adjustTempOffset();
void scd30_calibrate(uint16_t timeout);
bool scd30_softreset();
#endif

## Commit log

2020-12-14 first public release
    - firmware version 100
    - README is still missing details on hardware setup
    [CO2-Ampel.ino, logging.cpp, lorawan.cpp]
2020-12-20 added 3d-models and pics, fixed LICENSE
    [inner-frame.stl, sensor-mount.stl, ventilation-grille.stl]
2020-12-20 completed README, added web interface screenhots
    - added sections on hardware components, building the
    CO2-Ampel, its initial operation and sensor calibration
    - added screeshots from the web interface
2020-12-21 FastLED, html EN/DE, wifi/mqtt/led/rtc tweaks
    - led.cpp: use FastLED instead of Adafruit_NeoPixel
    - tweaked visual feedback with blink_led() on system startup
    - added battery voltage to LoRaWAN payload
    - added english html template (set LANG_DE or LANG_EN config.h)
    - wifi.cpp: explicitly check return values of WiFi system calls
    - mqtt.cpp: added systemID() to messages, omit readings on WARMUP/NODATA
    - rtc.h: make sure RTC is ready before function templates are called
    - webserver.cpp: sync check for username/password length with UI checks
    - sensor.h: lowered CO2_LOWER_BOUND to 350
    - temporarily disable password lauthentication for settings on reset
    - stop NTP sync before wifi_stop()
    - added t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
    [CO2-Ampel.ino, logging.cpp, lorawan.cpp]
2021-01-02 reworked loading/saving settings to EEPROM
    - reworked loading/saving of all settings structs (remove resetSettings()
    template, only save valid settings, moved crc16 to setDefaults())
    - all settings are now reset if the reset button the Wemos D1 is pressed
    - added logMsg() to enterDeepSleep()
    - also blink on mqtt publish success (orange) or failure (red)
    - added missing save_leds() to restore current state after blink_leds()
    - webui: if LoRaWAN is disabled, show "off" and hide devaddr/packets
    - webui: show build date and time on mouseover on firmware version number
    - version 102
    [CO2-Ampel.ino, lorawan.cpp, mqtt.cpp]
2021-01-02 added switch for RESTful option
    - added RESTful checkbox to network settings tab which enforces WiFi
    uplink if enabled (can be preset with ENABLE_REST in config.h)
    - added check for missing SSID in web ui if WiFI uplink is enabled
    - don't show the webserver timeout countdown if disabled
    - show number of published MQTT messages in web ui
    - also disable web handler for logging functions if switched off
    - call lmic_init() short after LoRaWAN has been enabled in web ui
    - fixed early logging in setup() before general settings are loaded
    - memset() settings structs on load() and reset()
    - leds_on() returns number of LEDs currently on
    - fixed masking keys in printHEX8bit()
    - added logMsg() for mq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
    [CO2-Ampel.ino, logging.cpp]
